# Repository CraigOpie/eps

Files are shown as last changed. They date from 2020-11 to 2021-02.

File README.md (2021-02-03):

# Electronic Power Supply
```

Vendor: Death Star Development, LLC
Date Created: August 1st, 2020
Version: 0.4.0

License: CC BY-NC-ND
Associated Filename: All
Associated Document: 
      https://github.com/craigopie/eps

```
------------------------------------------------------------------------------------
```

Disclaimer:

      This disclaimer is not a license and does not grant any rights to
      the materials distributed herewith. Except as otherwise provided in
      a valid license issued to you by DSD, and to the maximum extent
      permitted by applicable law: (1) THESE MATERIALS ARE MADE AVAILABLE
      "AS IS" AND WITH ALL FAULTS, AND DSD HEREBY DISCLAIMS ALL
      WARRANTIES AND CONDITIONS, EXPRESS, IMPLIED, OR STATUTORY,
      INCLUDING BUT NOT LIMITED TO THE WARRANTIES OF MERCHANTABILITY,
      NON-INFRINGEMENT, OR FITNESS FOR ANY PARTICULAR PURPOSE; and
      (2) DSD shall not be liable (whether in contract or tort,
      including negligence, or under any other theory of liability) for
      any loss or damage of any kind or nature related to, arising under
      or in connection with these materials, including any direct, or
      any indirect, special, incidental, or consequential loss or damage
      (including loss of data, profits, goodwill, or any type of loss or
      damage suffered as a result of any action brought by a third party)
      even if such damage or loss was reasonably foreseeable or DSD
      had been advised of the possibility of the same.

Critical Applications:

      DSD products are not designed or intended to be fail-safe, or
      for use in any application requiring fail-safe performance, such as
      life-support or safety devices or systems, Class III medical
      devices, nuclear facilities, applications related to the deployment
      of airbags, or any other applications that could lead to death,
      personal injury, or severe property or environmental damage
      (individually and collectively, "Critical Applications"). Customer
      assumes the sole risk and liability of any use of DSD products
      in Critical Applications, subject only to applicable laws and
      regulations governing limitations on product liability.

THIS COPYRIGHT NOTICE AND DISCLAIMER MUST BE RETAINED AS PART OF THIS
FILE AT ALL TIMES.

```
------------------------------------------------------------------------------------

# Overview

### Introduction

This repository provides a low cost Electronic Power Supply (EPS) in a PC-104 form factor that can be assembled by low experience individuals with limited soldering equipment.  The design provides the choice of using an Arduino controller or an ATSAM3X8E 32-bit processor.  The ATSAM3X8E provides more reliable I2C communications.  

### Notes

This version does not have a working WatchDog Timer.

### Features

Supports 8.2 Volt Batteries (2S Cell Lithium Based Chemistry).
* (6) Solar Pannel Connections
* (1) USB-C Connection for Programming
* (1) Arduino Nano Every as the Micro-Controller
* (3) 3V3 Switched Power Supplies (2A Max ea.)
* (2) 5V Switched Power Supplies (2A Max ea.)
* (1) 3V3 Bus Power Supply (2A Max)
* (1) 5V Bus Power Supply (2A Max)
* (1) I2C Bus Interface
* (1) Serial (UART) Interface

# Build

### Hardware

Please review the BOM and populate as required by referencing the schematic.  The 5V bus IC requires the supply and enable pins to be shorted together, using a solder bridge, during manufacturing.

### Firmware

Arduino: Be sure to flash the software and test the functionality prior to soldering on to the EPS. <br />
ATSAM3X8E: Please follow the documentation provided for the Arduino Due programming using the Native Port.

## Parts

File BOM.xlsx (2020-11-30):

Reference Designator | Value | Manufacturer Part Number | Digikey Part Number | Other Resource
C1 | 33pF | CL10C330JB8NNNC | 1276-1070-1-ND
C2, C3, C7 | 1uF | ‎CL10B105KA8NNNC | 1276-1184-1-ND
C33 | 22uF | T521V226M025ATE040 | 399-13114-1-ND
C34, C38, C39 | 4.7uF | CL31B475KAHNNNE | 1276-1055-1-ND
C4, C5, C64, C71, C72, C74, C75, C76, C77, C78, C79, C81, C83, C85, C86, C87, C88, C89, C90, C97 | 0.1uF | CL10B104KA8NNNC | 1276-1006-1-ND
C40, C43, C47, C52, C57, C58, C60, C61, C62 | 0.1uF | CL21B104KACNNNC | 1276-1099-1-ND
C41, C42, C48, C53, C59, C65, C66, C67, C68, C69 | 1uF | CL21B105KOFNNNG | 1276-6471-1-ND
C44, C49, C54 | 10pF | CL21C100CBANNNC | 1276-2561-1-ND
C45, C50, C55 | 47uF | CL32A476KOJNNNE | 1276-3376-1-ND
C46, C51, C56 | 4.7uF | CL21A475KAQNNNE | 1276-1244-1-ND
C6, C9 | 10uF | CL31B106MOHNNNE | 1276-6641-1-ND
C63 | 10000pF | CL21B103KBANNNC | 1276-1015-1-ND
C70, C73, C80, C82, C84, C98 | 22uF | CL10A226MO7JZNC | 1276-7076-1-ND
C8, C10, C101 | 4.7uF | CL10A475KO8NNNC | 1276-1784-1-ND
C91 | 10000pF | CL10B103KB8NNNC | 1276-1009-1-ND
C92, C93, C94, C95, C96 | 22pF | CL10C220JB8NFNC | 1276-2228-1-ND
D1, D2, D3, D4, D5, D6, D7 | DNP | MBR2H100SFT3G | MBR2H100SFT3GOSCT-ND
D8 | 1N5819HW | 1N5819HW-7-F | 1N5819HW-FDICT-ND
FB3 | 330 | BLM21SP331SH1D | 490-18586-1-ND
FB4, FB5, FB6, FB7 | MH2029-300Y | MH2029-300Y | MH2029-300YCT-ND
J7 | CONN_2X5_127 | 20021121-00010C4LF | 609-3695-1-ND
J8 | USB-C | UJ31-CH-G1-SMT-TR | 102-4488-1-ND
L1 | IND-FXL0630 | FXL0630-2R2-M |  | https://lcsc.com/product-detail/Power-Inductors_Changjiang-Microelectronics-Tech-FXL0630-2R2-M_C167218.html
L4, L5, L6 | 2.2uH | XFL4020-222MEC |  | https://www.mouser.com/ProductDetail/Coilcraft/XFL4020-222MEC?qs=zCSbvcPd3pbe5jEAG1ZkEA%3D%3D
M1 | A03400 | A03400 |  | https://lcsc.com/product-detail/MOSFET_KEXIN-AO3400_C382311.html
R1, R10, R44 | 10K | RC1608J103CS | 1276-5086-1-ND
R15, R16, R18, R70 | 1K | RC1608F102CS | 1276-3484-1-ND
R17 | 100 | RC1608F101CS | 1276-3482-1-ND
R2 | 40.2K | RC1608F4022CS | 1276-4800-1-ND
R3 | 86.6K / 84.5K | RC1608F8452CS | 1276-4833-1-ND
R31, R32, R33, R34, R60 | 1M | RC1608J105CS | 1276-5134-1-ND
R39, R45, R51 | 18.2K | RC2012F1822CS | 1276-5349-1-ND
R4 | 71.5K / 68.1K | RC1608F6812CS | 1276-4824-1-ND
R40, R48 | 182K / 180K | RC2012F184CS | 1276-5408-1-ND
R41, R47, R53 | 1.0M | RC2012F105CS | 1276-5440-1-ND
R42, R46, R52 | 49.9K / 47K | RC2012J473CS | 1276-5568-1-ND
R43, R50, R56, R62, R63, R64, R69, R75, R76 | 100K | RC1608J104CS | 1276-5110-1-ND
R5 | 15K | RC2012J153CS | 1276-5556-1-ND
R54 | 300K / 301K | RC2012F3013CS | 1276-5424-1-ND
R55 | 62K / 63.4K | RC2012F6342CS | 1276-5383-1-ND
R59 | 127K / 130K | RC2012F134CS | 1276-5400-1-ND
R6, R37, R38, R57 | 10K | RC2012F103CS | 1276-5332-1-ND
R61 | 191K / 180K | RC2012F184CS | 1276-5408-1-ND
R65, R66 | 39R 1% | RC1608F390CS | 1276-4531-1-ND
R67 | 6.8K | RC1608F6811CS | 1276-4729-1-ND
R68 | 0 | RC1005J000CS | 1276-3480-1-ND
R7, R8, R30, R36, R58 | 2K | RC1608F202CS | 1276-3495-1-ND
R73, R74 | 5.1K | RC1608F512CS | 1276-4713-1-ND
R9 | 27.4K | RC1608F2742CS | 1276-4782-1-ND
R99 | 0 | CRCW20100000Z0EF | 541-0.0WCT-ND
TB1 | ARDUINO_NANO | ARDUINO_NANO
U1 | MP2639A | MP2639AGR-Z | 1589-1618-1-ND
U11 | ADT7311 | ADT7311WTRZ-RL7 | ADT7311WTRZ-RL7CT-ND
U12 | MAX16998AAUA+ | MAX16998AAUA+ | MAX16998AAUA+-ND
U13 | Value | TPS27082LDDCR | 296-35595-1-ND
U14 | ATSAM3X8EA-AU | ATSAM3X8EA-AU | ATSAM3X8EA-AU-ND
U15, U18 | PMV48XP | PMV48XPAR | 1727-2308-1-ND
U16 | BC847B-7-F | BC847B-7-F | BC847B-7FDICT-ND
U17 | LMV358IDGKR | LMV358IDGKR | 296-13455-1-ND
U19 | NCP1117ST33T3G | NCP1117ST33T3G | NCP1117ST33T3GOSCT-ND
U2 | TCA9511A | TCA9511A | 296-TCA9511ADGKRCT-ND
U3, U4, U5 | LT8609A | LT8609A | LT8609AEMSE#TRPBFCT-ND
U6, U7, U8, U9, U10 | LTC1477 | LTC1477 | LTC1477CS8#TRPBFCT-ND
Y1 | ABM8 | ABM8-12.000MHZ-12-B1U-T | 535-14962-1-ND
Y2 | FC-135R | FC-135R 32.7680KF-A3 | SER4076CT-ND

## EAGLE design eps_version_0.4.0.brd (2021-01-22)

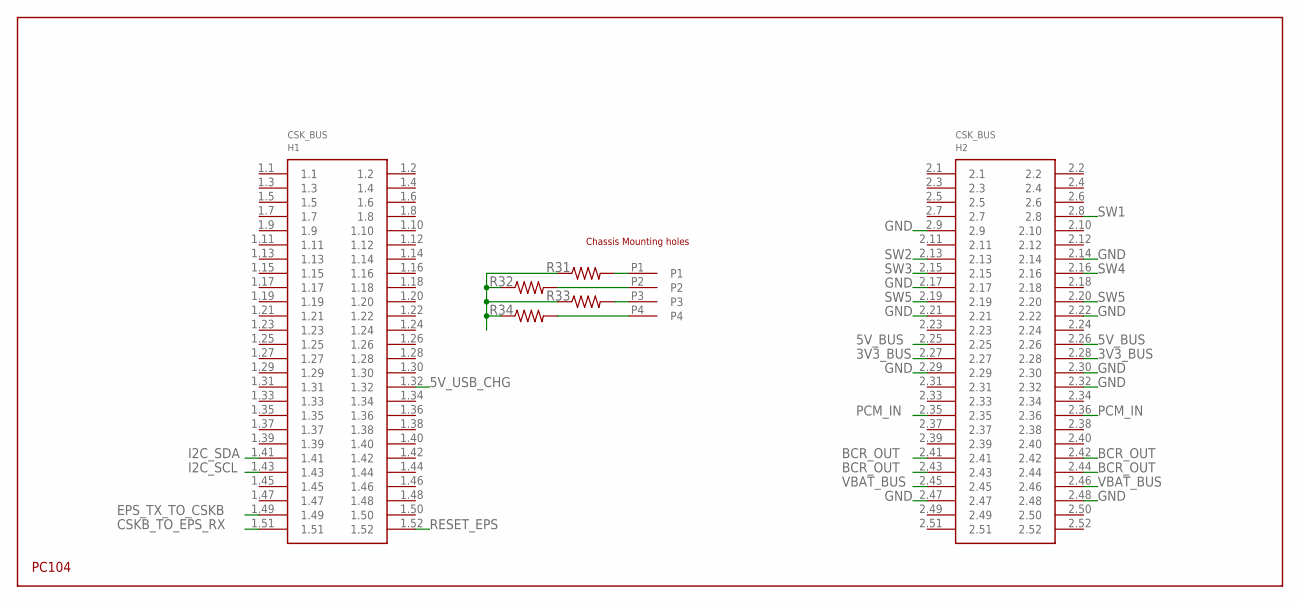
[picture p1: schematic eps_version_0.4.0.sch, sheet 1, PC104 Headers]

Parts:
H1: PC104_WCONN
R31, R32, R33, R34: 1M; 0805

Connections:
3V3_BUS: H1.2.27, H1.2.28; also elsewhere on the board
5V_BUS: H1.2.25, H1.2.26; also elsewhere on the board
5V_USB_CHG: H1.1.32; also elsewhere on the board
BCR_OUT: H1.2.41, H1.2.42, H1.2.43, H1.2.44; also elsewhere on the board
CSKB_TO_EPS_RX: H1.1.51; also elsewhere on the board
EPS_TX_TO_CSKB: H1.1.49; also elsewhere on the board
GND: H1.2.9, H1.2.14, H1.2.17, H1.2.21, H1.2.22, H1.2.29, H1.2.30, H1.2.32, H1.2.47, H1.2.48, R31.1, R32.1, R33.1, R34.1; also elsewhere on the board
I2C_SCL: H1.1.43; also elsewhere on the board
I2C_SDA: H1.1.41; also elsewhere on the board
P1_R31: H1.P1, R31.2
P2_R32: H1.P2, R32.2
P3_R33: H1.P3, R33.2
P4_R34: H1.P4, R34.2
PCM_IN: H1.2.35, H1.2.36; also elsewhere on the board
RESET_EPS: H1.1.52; also elsewhere on the board
SW1: H1.2.8; also elsewhere on the board
SW2: H1.2.13; also elsewhere on the board
SW3: H1.2.15; also elsewhere on the board
SW4: H1.2.16; also elsewhere on the board
SW5: H1.2.19, H1.2.20; also elsewhere on the board
VBAT_BUS: H1.2.45, H1.2.46; also elsewhere on the board

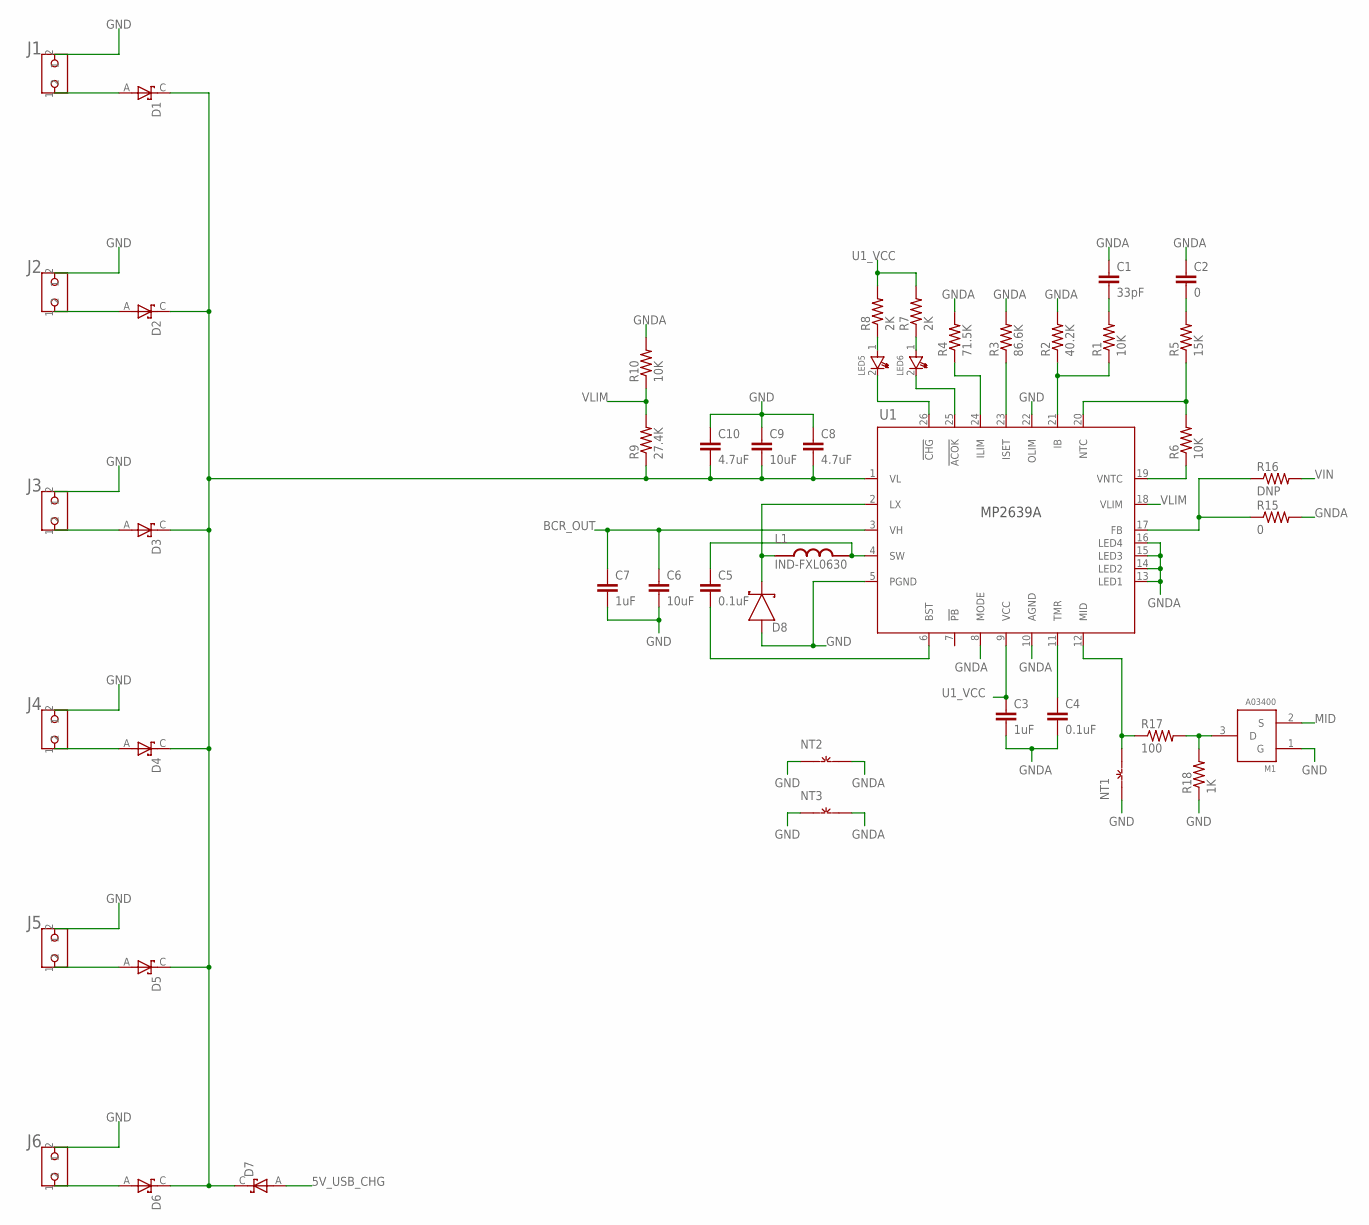
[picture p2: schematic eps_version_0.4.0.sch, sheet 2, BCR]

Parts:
C1: 33pF; 0603-CAP
C2: 0; 0603-CAP
C3, C7: 1uF; 0603-CAP
C4, C5: 0.1uF; 0603-CAP
C6, C9: 10uF; 1206
C8, C10: 4.7uF; 0603-CAP
D1, D2, D3, D4, D5, D6, D7: DNP; SODFL3616X98N
D8: 1N5819HW; SOD123
J1, J2, J3, J4, J5, J6: 2PIN_HEADER; 2MM_2PIN_HEADER
L1: IND-FXL0630; FXL0630
LED5, LED6: LED_0805
M1: A03400; SOT23
NT1, NT2, NT3: GND-GNDA1,27MM; GND-GNDA-1,27MM
R1, R10: 10K; 0603-RES
R2: 40.2K; 0603-RES
R3: 86.6K; 0603-RES
R4: 71.5K; 0603-RES
R5: 15K; 0805
R6: 10K; 0805
R7, R8: 2K; 0603-RES
R9: 27.4K; 0603-RES
R15: 0; 0603-RES
R16: DNP; 0603-RES
R17: 100; 0603-RES
R18: 1K; 0603-RES
U1: MP2639A; IC26_MP2639A_MNP

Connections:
5V_USB_CHG: D7.A; also elsewhere on the board
!ACOK: LED6.2, U1.25 (!ACOK)
!CHG: LED5.2, U1.26 (!CHG)
BCR_OUT: C6.1, C7.1, U1.3 (VH); also elsewhere on the board
BST: C5.2, U1.6 (BST)
C1_R1: C1.2, R1.2
GND: C6.2, C7.2, C8.1, C9.1, C10.1, D8.2 (1), J1.2, J2.2, J3.2, J4.2, J5.2, J6.2, M1.1 (G), NT1.GND, NT2.GND, NT3.GND, R18.1, U1.5 (PGND), U1.22 (OLIM); also elsewhere on the board
GNDA: C1.1, C2.1, C3.2, C4.2, NT2.GNDA, NT3.GNDA, R2.2, R3.2, R4.2, R10.2, R15.2, U1.8 (MODE), U1.10 (AGND), U1.13 (LED1), U1.14 (LED2), U1.15 (LED3), U1.16 (LED4)
IB: R1.1, R2.1, U1.21 (IB)
ILIM: R4.1, U1.24 (ILIM)
ISET: R3.1, U1.23 (ISET)
LX: D8.1 (2), L1.1, U1.2 (LX)
MID: M1.2 (S), NT1.GNDA, R17.1, U1.12 (MID)
NTC: R5.1, R6.2, U1.20 (NTC)
R5_C2: C2.2, R5.2
R7_LED6: LED6.1, R7.1
R8_LED5: LED5.1, R8.1
R17_R18: M1.3 (D), R17.2, R18.2
SA1AIN: D1.A, J1.1
SA1BIN: D2.A, J2.1
SA2AIN: D3.A, J3.1
SA2BIN: D4.A, J4.1
SA3AIN: D5.A, J5.1
SA3BIN: D6.A, J6.1
TMR: C4.1, U1.11 (TMR)
U1_FB: R15.1, R16.1, U1.17 (FB)
U1_SW: C5.1, L1.2, U1.4 (SW)
U1_VCC: C3.1, R7.2, R8.2, U1.9 (VCC)
VIN: C8.2, C9.2, C10.2, D1.C, D2.C, D3.C, D4.C, D5.C, D6.C, D7.C, R9.1, R16.2, U1.1 (VL)
VLIM: R9.2, R10.1, U1.18 (VLIM)
VNTC: R6.1, U1.19 (VNTC)

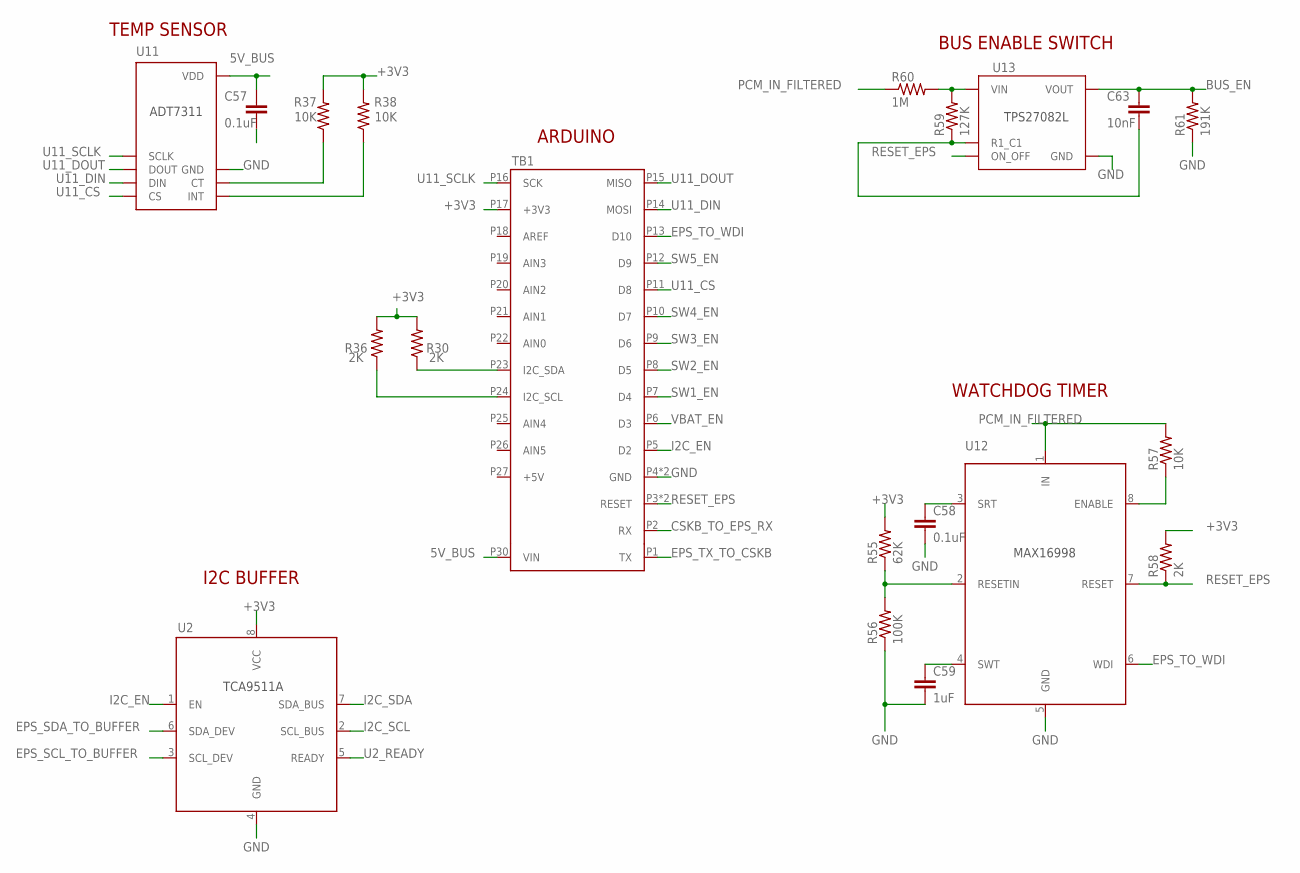
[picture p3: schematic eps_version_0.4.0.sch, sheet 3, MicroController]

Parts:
C57, C58: 0.1uF; 0805
C59: 1uF; 0805
C63: 10nF; 0805
R30, R36, R58: 2K; 0805
R37, R38, R57: 10K; 0805
R55: 62K; 0805
R56: 100K; 0805
R59: 127K; 0805
R60: 1M; 0805
R61: 191K; 0805
TB1: ARDUINO_NANO; SHIELD_ARDUINO_NANO
U2: TCA9511A; SOP65P490X110-8N
U11: ADT7311; SOIC-8
U12: MAX16998AAUA+; 21-0036K_MXM
U13: Value; DDC0006A_N

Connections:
5V_BUS: C57.1, TB1.P30 (VIN), U11.8 (VDD); also elsewhere on the board
+3V3: R30.2, R36.2, R37.2, R38.2, R55.2, R58.2, TB1.P17 (+3V3), U2.8 (VCC)
BUS_EN: C63.1, R61.2, U13.2 (VOUT), U13.3 (VOUT); also elsewhere on the board
CSKB_TO_EPS_RX: TB1.P2 (RX); also elsewhere on the board
EPS_SCL_TO_BUFFER: R36.1, TB1.P24 (I2C_SCL), U2.3 (SCL_DEV); also elsewhere on the board
EPS_SDA_TO_BUFFER: R30.1, TB1.P23 (I2C_SDA), U2.6 (SDA_DEV); also elsewhere on the board
EPS_TO_WDI: TB1.P13 (D10), U12.6 (WDI); also elsewhere on the board
EPS_TX_TO_CSKB: TB1.P1 (TX); also elsewhere on the board
GND: C57.2, C58.2, C59.2, R56.1, R61.1, TB1.P4 (GND), TB1.P29 (GND), U2.4 (GND), U11.7 (GND), U12.5 (GND), U13.1 (GND); also elsewhere on the board
I2C_EN: TB1.P5 (D2), U2.1 (EN); also elsewhere on the board
I2C_SCL: U2.2 (SCL_BUS); also elsewhere on the board
I2C_SDA: U2.7 (SDA_BUS); also elsewhere on the board
PCM_IN_FILTERED: R57.2, R60.1, U12.1 (IN); also elsewhere on the board
PCM_IN_FILTERED_TO_BUS_EN: R59.2, R60.2, U13.4 (VIN)
RESET_EPS: R58.1, TB1.P3 (RESET), TB1.P28 (RESET), U12.7 (RESET), U13.5 (ON_OFF); also elsewhere on the board
SW1_EN: TB1.P7 (D4); also elsewhere on the board
SW2_EN: TB1.P8 (D5); also elsewhere on the board
SW3_EN: TB1.P9 (D6); also elsewhere on the board
SW4_EN: TB1.P10 (D7); also elsewhere on the board
SW5_EN: TB1.P12 (D9); also elsewhere on the board
U2_READY: U2.5 (READY)
U11_CS: TB1.P11 (D8), U11.4 (CS); also elsewhere on the board
U11_CT: R37.1, U11.6 (CT)
U11_DIN: TB1.P14 (MOSI), U11.3 (DIN); also elsewhere on the board
U11_DOUT: TB1.P15 (MISO), U11.2 (DOUT); also elsewhere on the board
U11_INT: R38.1, U11.5 (INT)
U11_SCLK: TB1.P16 (SCK), U11.1 (SCLK); also elsewhere on the board
U12_EN_ALT: R57.1, U12.8 (ENABLE)
U12_RESETIN: R55.1, R56.2, U12.2 (RESETIN)
U12_SRT: C58.1, U12.3 (SRT)
U12_SWT: C59.1, U12.4 (SWT)
U13_R60_C63: C63.2, R59.1, U13.6 (R1_C1)
VBAT_EN: TB1.P6 (D3); also elsewhere on the board

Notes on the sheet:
I2C BUFFER
ARDUINO
TEMP SENSOR
WATCHDOG TIMER
BUS ENABLE SWITCH

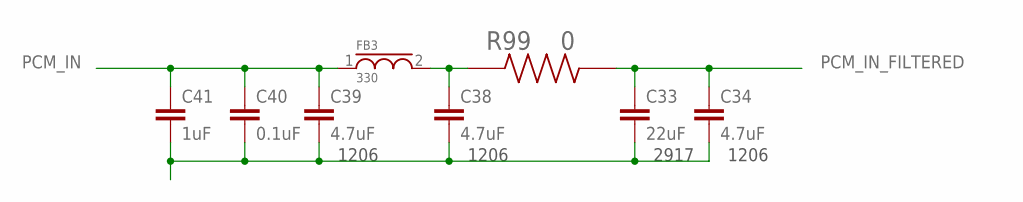
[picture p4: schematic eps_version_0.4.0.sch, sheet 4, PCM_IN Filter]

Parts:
C33: 22uF; CAPMP7343X430N
C34, C38, C39: 4.7uF; 1206
C40: 0.1uF; 0805
C41: 1uF; 0805
FB3: 330; 0805
R99: 0; RESC5025X70N

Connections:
FB3_L3: C38.1, FB3.2, R99.1
GND: C33.2, C34.2, C38.2, C39.2, C40.2, C41.2; also elsewhere on the board
PCM_IN: C39.1, C40.1, C41.1, FB3.1; also elsewhere on the board
PCM_IN_FILTERED: C33.1, C34.1, R99.2; also elsewhere on the board

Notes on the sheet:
1206
2917

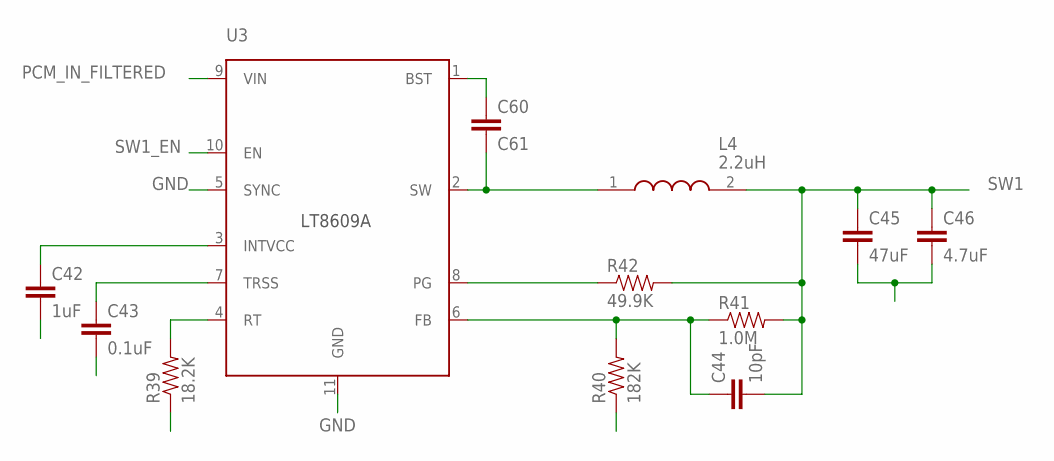
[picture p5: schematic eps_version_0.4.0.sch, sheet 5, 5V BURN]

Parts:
C42: 1uF; 0805
C43: 0.1uF; 0805
C44: 10pF; 0805
C45: 47uF; 1210
C46: 4.7uF; 0805
C60: C61; 0805
L4: 2.2uH; XFL4030472MEB
R39: 18.2K; 0805
R40: 182K; 0805
R41: 1.0M; 0805
R42: 49.9K; 0805
U3: LT8609A; MSOP-10_MSE

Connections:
FB_SW1: C44.1, R40.2, R41.1, U3.6 (FB)
GND: C42.2, C43.2, C45.2, C46.2, R39.1, R40.1, U3.5 (SYNC), U3.11 (GND); also elsewhere on the board
PCM_IN_FILTERED: U3.9 (VIN); also elsewhere on the board
PG_SW1: R42.1, U3.8 (PG)
RT_SW1: R39.2, U3.4 (RT)
SW1: C44.2, C45.1, C46.1, L4.2, R41.2, R42.2; also elsewhere on the board
SW1_EN: U3.10 (EN); also elsewhere on the board
SW_SW1: C60.2, L4.1, U3.2 (SW)
TRSS_SW1: C43.1, U3.7 (TRSS)
U3_BST: C60.1, U3.1 (BST)
VCC_SW1: C42.1, U3.3 (INTVCC)

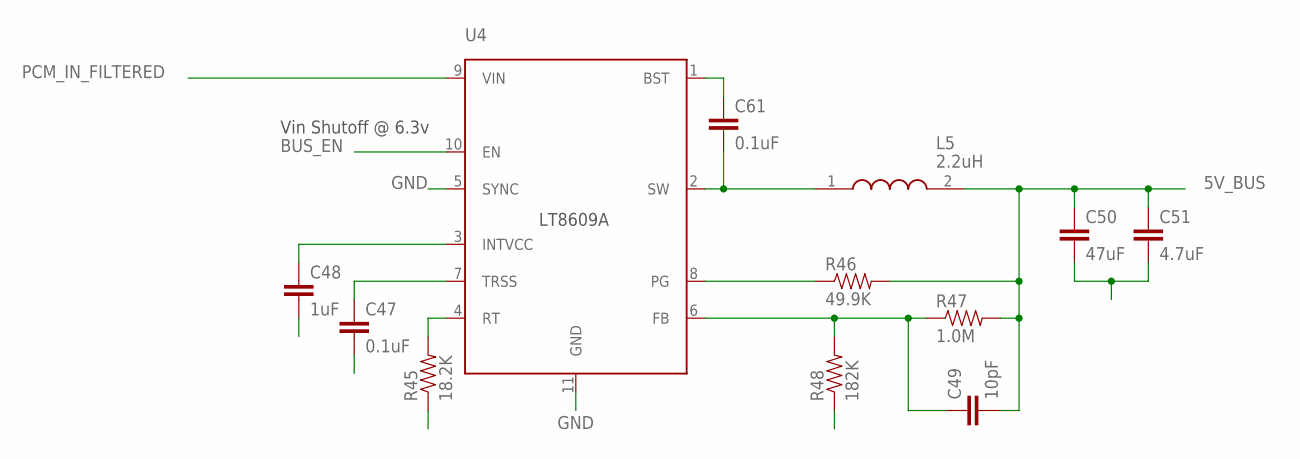
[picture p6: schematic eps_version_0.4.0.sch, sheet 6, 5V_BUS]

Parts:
C47, C61: 0.1uF; 0805
C48: 1uF; 0805
C49: 10pF; 0805
C50: 47uF; 1210
C51: 4.7uF; 0805
L5: 2.2uH; XFL4030472MEB
R45: 18.2K; 0805
R46: 49.9K; 0805
R47: 1.0M; 0805
R48: 182K; 0805
U4: LT8609A; MSOP-10_MSE

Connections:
5V_BUS: C49.2, C50.1, C51.1, L5.2, R46.2, R47.2; also elsewhere on the board
BST_5V_BUS: C61.1, U4.1 (BST)
BUS_EN: U4.10 (EN); also elsewhere on the board
FB_5V_BUS: C49.1, R47.1, R48.2, U4.6 (FB)
GND: C47.2, C48.2, C50.2, C51.2, R45.1, R48.1, U4.5 (SYNC), U4.11 (GND); also elsewhere on the board
PCM_IN_FILTERED: U4.9 (VIN); also elsewhere on the board
PG_5V_BUS: R46.1, U4.8 (PG)
RT_5V_BUS: R45.2, U4.4 (RT)
SW_5V_BUS: C61.2, L5.1, U4.2 (SW)
TRSS_5V_BUS: C47.1, U4.7 (TRSS)
VCC_5V_BUS: C48.1, U4.3 (INTVCC)

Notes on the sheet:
Vin Shutoff @ 6.3v

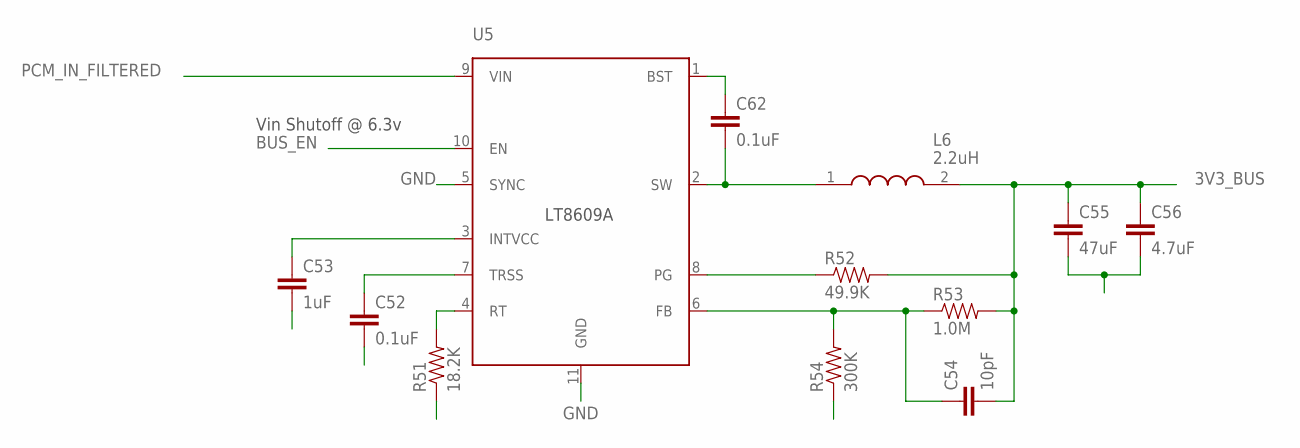
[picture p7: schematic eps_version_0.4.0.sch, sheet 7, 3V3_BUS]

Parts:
C52, C62: 0.1uF; 0805
C53: 1uF; 0805
C54: 10pF; 0805
C55: 47uF; 1210
C56: 4.7uF; 0805
L6: 2.2uH; XFL4030472MEB
R51: 18.2K; 0805
R52: 49.9K; 0805
R53: 1.0M; 0805
R54: 300K; 0805
U5: LT8609A; MSOP-10_MSE

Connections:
3V3_BUS: C54.2, C55.1, C56.1, L6.2, R52.2, R53.2; also elsewhere on the board
BST_3V3_BUS: C62.1, U5.1 (BST)
BUS_EN: U5.10 (EN); also elsewhere on the board
FB_3V3_BUS: C54.1, R53.1, R54.2, U5.6 (FB)
GND: C52.2, C53.2, C55.2, C56.2, R51.1, R54.1, U5.5 (SYNC), U5.11 (GND); also elsewhere on the board
PCM_IN_FILTERED: U5.9 (VIN); also elsewhere on the board
PG_3V3_BUS: R52.1, U5.8 (PG)
RT_3V3_BUS: R51.2, U5.4 (RT)
SW_3V3_BUS: C62.2, L6.1, U5.2 (SW)
TRSS_3V3_BUS: C52.1, U5.7 (TRSS)
VCC_3V3_BUS: C53.1, U5.3 (INTVCC)

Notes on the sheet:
Vin Shutoff @ 6.3v

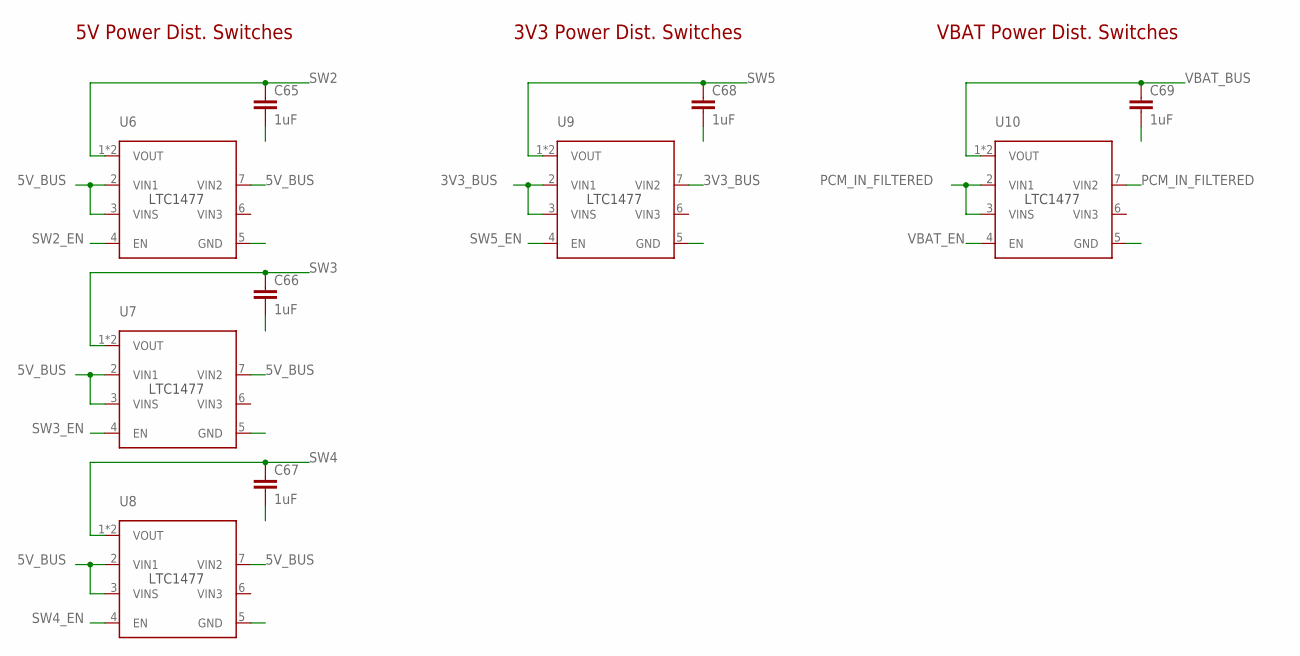
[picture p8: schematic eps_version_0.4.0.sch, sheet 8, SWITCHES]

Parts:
C65, C66, C67, C68, C69: 1uF; 0805
U6, U7, U8, U9, U10: LTC1477; SO8

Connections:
3V3_BUS: U9.2 (VIN1), U9.3 (VINS), U9.7 (VIN2); also elsewhere on the board
5V_BUS: U6.2 (VIN1), U6.3 (VINS), U6.7 (VIN2), U7.2 (VIN1), U7.3 (VINS), U7.7 (VIN2), U8.2 (VIN1), U8.3 (VINS), U8.7 (VIN2); also elsewhere on the board
GND: C65.2, C66.2, C67.2, C68.2, C69.2, U6.5 (GND), U7.5 (GND), U8.5 (GND), U9.5 (GND), U10.5 (GND); also elsewhere on the board
PCM_IN_FILTERED: U10.2 (VIN1), U10.3 (VINS), U10.7 (VIN2); also elsewhere on the board
SW2: C65.1, U6.1 (VOUT), U6.8 (VOUT); also elsewhere on the board
SW2_EN: U6.4 (EN); also elsewhere on the board
SW3: C66.1, U7.1 (VOUT), U7.8 (VOUT); also elsewhere on the board
SW3_EN: U7.4 (EN); also elsewhere on the board
SW4: C67.1, U8.1 (VOUT), U8.8 (VOUT); also elsewhere on the board
SW4_EN: U8.4 (EN); also elsewhere on the board
SW5: C68.1, U9.1 (VOUT), U9.8 (VOUT); also elsewhere on the board
SW5_EN: U9.4 (EN); also elsewhere on the board
VBAT_BUS: C69.1, U10.1 (VOUT), U10.8 (VOUT); also elsewhere on the board
VBAT_EN: U10.4 (EN); also elsewhere on the board

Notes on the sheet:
5V Power Dist. Switches
3V3 Power Dist. Switches
VBAT Power Dist. Switches

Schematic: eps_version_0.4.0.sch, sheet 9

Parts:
C64, C71, C72, C74, C75, C76, C77, C78, C79, C81, C83, C85, C86, C87, C88, C89, C90, C97: 100nF; 0603-CAP
C70, C73, C80, C82, C84, C98: 22uF; 0603-CAP
C91: 10nF; 0603-CAP
C92, C93, C94, C95, C96: 22pF; 0603-CAP
C101: 4.7uF; 0603-CAP
FB4, FB5: MH2029-300Y; 0805
FB6, FB7: FB0805; 0805
J7: CONN_2X5_127; 2X5_127
J8: USB-C; CUI_UJ31-CH-G1-SMT-TR
R43, R50, R62, R63, R64, R69, R75, R76: 100K; 0603-RES
R44: 10K; 0603-RES
R65, R66: 39R 1%; 0603-RES
R67: 6.8K; 0603-RES
R68: 0; 0402-RES
R70: 1K; 0603-RES
R73, R74: 5.1K; 0603-RES
U14: ATSAM3X8EA-AU; LQFP144
U15: PMV48XP; TO-236_SOT23_NEX
U16: BC847B-7-F; TO-236_SOT23_NEX
U17: LMV358IDGKR; DGK8
U18: PMV48XP,215; TO-236_SOT23_NEX
U19: NCP1117ST33T3G; SOT223-3_ONS
Y1: ABM8
Y2: FC-135R; FC-135

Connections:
3V3: C72.1, C73.1, C74.1, C75.1, C76.1, C77.1, C78.1, C79.1, C91.1, C98.1, FB5.1, FB6.1, FB7.1, J7.1, R43.2, R44.2, R50.2, R62.2, R63.2, R64.2, U14.11 (VDDIO1), U14.52 (VDDBU), U14.57 (VDDIN), U14.62 (VDDIO2), U14.105 (VDDIO3), U14.125 (VDDIO4), U15.2 (S), U17.6 (2IN-), U19.2 (OUT)
5V_BUS: R69.2, U17.8 (VCC+), U18.2 (S), U19.3 (IN); also elsewhere on the board
5V_BUS_U17_+: C97.1, R69.1, R76.2, U16.3 (C), U17.5 (2IN+)
AVREF: C64.1, FB5.2, U14.75 (ADVREF)
CC1: J8.A5 (CC1), R74.2
CC2: J8.B5 (CC2), R73.2
CSKB_TO_EPS_RX: U14.27 (PA8); also elsewhere on the board
EPS_SCL_TO_BUFFER: U14.70 (PA18); also elsewhere on the board
EPS_SDA_TO_BUFFER: U14.9 (PA17); also elsewhere on the board
EPS_TO_WDI: U14.144 (PB25); also elsewhere on the board
EPS_TX_TO_CSKB: U14.2 (PA9); also elsewhere on the board
ERASE_CMD: R44.1, U15.1 (G)
ERASE_S: U14.130 (PC0), U15.3 (D)
FWUP_R43: R43.1, U14.53 (FWUP)
GND: C64.2, C70.2, C71.2, C72.2, C73.2, C74.2, C75.2, C76.2, C77.2, C78.2, C79.2, C80.2, C81.2, C82.2, C83.2, C84.2, C85.2, C86.2, C87.2, C88.2, C89.2, C90.2, C92.2, C93.1, C94.2, C95.2, C96.1, C97.2, C98.2, C101.2, J7.3, J7.5, J7.9, J8.A1 (GND), J8.A12 (GND), J8.B1 (GND), J8.B12 (GND), J8.SH1 (SHIELD), J8.SH2 (SHIELD), J8.SH3 (SHIELD), J8.SH4 (SHIELD), J8.SH5 (SHIELD), J8.SH6 (SHIELD), R67.1, R68.1, R73.1, R74.1, R75.1, R76.1, U14.12 (GND1), U14.33 (GNDPLL), U14.44 (GNDUTMI), U14.46 (JTAGSEL), U14.54 (GNDBU), U14.58 (GND2), U14.74 (GNDANA), U14.106 (GND3), U14.126 (GND4), U16.2 (E), U17.4 (GND), U19.1 (GND), Y1.2, Y1.4; also elsewhere on the board
I2C_EN: U14.139 (PC28); also elsewhere on the board
JTAG_TCK: J7.4, R62.1, U14.28 (PB28)
JTAG_TDI: J7.8, R63.1, U14.29 (PB29)
JTAG_TDO: J7.6, U14.30 (PB30)
JTAG_TMS: J7.2, R50.1, U14.31 (PB31)
R65_DFSDM: R65.2, U14.43 (DFSDM)
R66_DFSDP: R66.2, U14.42 (DFSDP)
R68_TST: R68.2, U14.51 (TST)
R70_U16_BASE: R70.2, R75.2, U16.1 (B)
RESET_EPS: C91.2, J7.10, R64.1, U14.47 (NRSTB); also elsewhere on the board
SW1_EN: U14.136 (PC25); also elsewhere on the board
SW2_EN: U14.135 (PC24); also elsewhere on the board
SW3_EN: U14.134 (PC23); also elsewhere on the board
SW4_EN: U14.133 (PC22); also elsewhere on the board
SW5_EN: U14.132 (PC21); also elsewhere on the board
U11_CS: U14.111 (PA28); also elsewhere on the board
U11_DIN: U14.20 (PD7); also elsewhere on the board
U11_DOUT: U14.21 (PD8); also elsewhere on the board
U11_SCLK: U14.88 (PB17); also elsewhere on the board
U17_U18: U17.7 (2OUT), U18.1 (G)
USB_DM: J8.A7 (DN1), J8.B7 (DN2), R65.1, U14.38 (DHSDM)
USB_DP: J8.A6 (DP1), J8.B6 (DP2), R66.1, U14.37 (DHSDP)
USB_OTG_ID: U14.129 (PB11)
USB_OTG_VBOF: R70.1, U14.128 (PB10)
USB_VBUS: C101.1, J8.A4 (VBUS), J8.A9 (VBUS), J8.B4 (VBUS), J8.B9 (VBUS), U14.39 (VBUS), U18.3 (D)
VBAT_EN: U14.112 (PA29); also elsewhere on the board
VBG: C92.1, R67.2, U14.40 (VBG)
VDDANA: C80.1, C81.1, FB6.2, U14.73 (VDDANA)
VDDOUT: C84.1, C85.1, C86.1, C87.1, C88.1, C89.1, C90.1, FB4.1, U14.10 (VDDCORE1), U14.45 (VDDCORE2), U14.56 (VDDOUT), U14.61 (VDDCORE3), U14.104 (VDDCORE4), U14.124 (VDDCORE5)
VDDOUTMI: C82.1, C83.1, FB7.2, U14.41 (VDDOUTMI)
VDDPLL: C70.1, C71.1, FB4.2, U14.34 (VDDPL)
XIN: C93.2, U14.36 (XIN), Y1.3
XIN32: C96.2, U14.48 (XIN32), Y2.2
XOUT: C94.1, U14.35 (XOUT), Y1.1
XOUT32: C95.1, U14.49 (XOUT32), Y2.1

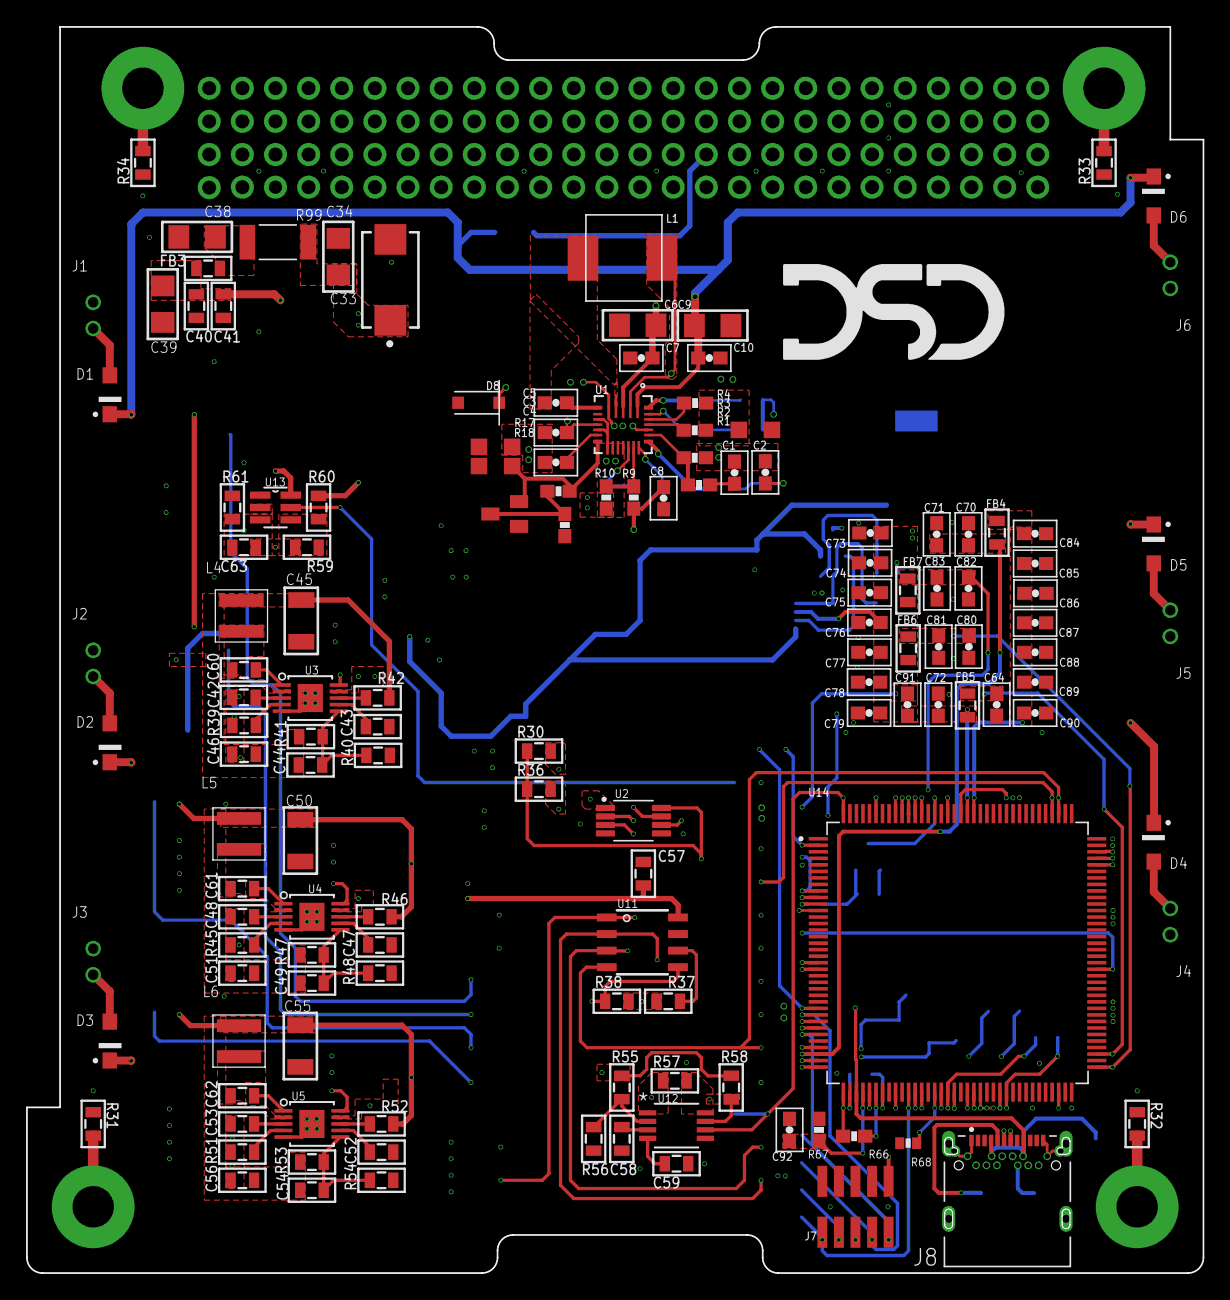
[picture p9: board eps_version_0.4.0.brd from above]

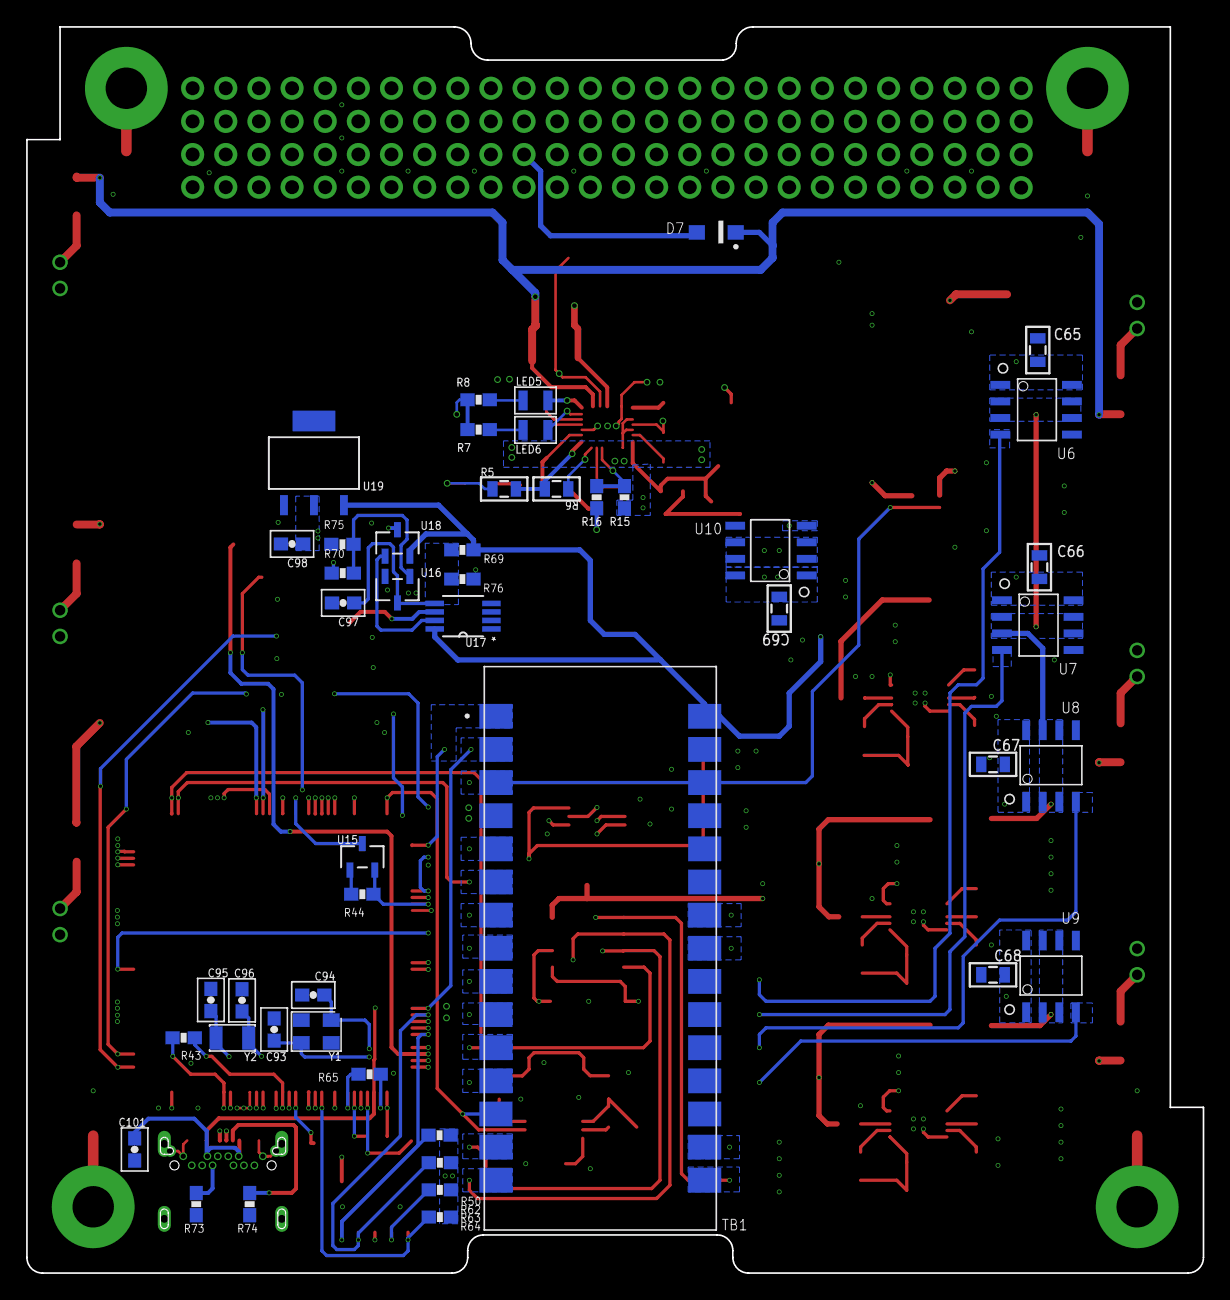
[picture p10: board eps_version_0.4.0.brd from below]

Board: 4 copper layers, 90.2 x 95.5 mm, 186 parts (47 on the bottom side), 126 nets.

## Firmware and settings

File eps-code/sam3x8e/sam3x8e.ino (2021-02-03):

/********************************************************************
 *   
 *   DSD EPS Software
 *   
 *******************************************************************   
 *******************************************************************
 *   Purpose
 *   
 *   Sketch to operate DSD EPS                      
 *                                                                  
 *   Program editors:                                               
 *     Craig Opie                                                   
 *                                                                  
 *******************************************************************/
/********************************************************************
 *   Editing history
 *   
 *   08/04/20 - Version 0.1.0 - Craig:
 *   Initial Draft.
 *   - Standard object code and methods
 *              
 *******************************************************************/
/********************************************************************
 *   Hardware compatibility
 *   
 *   DSD EPS v0.4.0
 *   Arduino Nano Every
 *   
 *******************************************************************/


/********************************************************************
 *   Includes
 *******************************************************************/
#include <Wire.h>


/********************************************************************
 *   Definitions
 *******************************************************************/
#define I2C_ADDRESS                           0x2b
#define BOARD_STATUS                          0x01
#define GET_LAST_ERROR                        0x03
#define GET_VERSION                           0x04
#define GET_TELEMETRY                         0x10
#define GET_WATCHDOG                          0x20
#define SET_WATCHDOG                          0x21
#define RESET_WATCHDOG                        0x22
#define ALL_PDMS_ON                           0x40
#define ALL_PDMS_OFF                          0x41
#define GET_PDMS_ACTUAL                       0x42
#define GET_PDMS_EXPECTED                     0x43
#define SET_PDM_ON                            0x50
#define SET_PDM_OFF                           0x51
#define EPS_RESET                             0x80

#define UART                                  Serial
#define I2C                                   Wire
#define I2C_ENABLE                            139
#define VBAT_ENABLE                           137
#define SW1_ENABLE                            136
#define SW2_ENABLE                            135
#define SW3_ENABLE                            134
#define SW4_ENABLE                            133
#define SW5_ENABLE                            132
#define WDT_RESET                             144

#define MAX_I2C_BYTES                         16


/********************************************************************
 *   Setup Object Links/Pointers
 *******************************************************************/
class DSD_EPS
{
  private:
    unsigned long watchdog_limit;
    unsigned long watchdog_last_reset;
    unsigned long watchdog_internal;
    bool reset_eps;
    int pdm_expected;
    int pdm_status;
    int board_status;
    int last_error;
    void gpioHigh(int);
    void gpioLow(int);
    void boardStatus();
    void getLastError();
    void getVersion();
    void getTelemetry();
    void getWatchdog();
    void setWatchdog();
    void resetWatchdog();
    void allPDMsOn();
    void allPDMsOff();
    void getPDMsActual();
    void getPDMsExpected();
    void setPDMOn();
    void setPDMOff();
    void epsReset();

  public:
    bool i2c_receive;
    bool i2c_request;
    byte i2c_data[MAX_I2C_BYTES];
    int bytes;
    DSD_EPS();
    ~DSD_EPS();
    void init();
    void readI2C();
    void readUART();
    void watchdog();
 
};


/********************************************************************
 *   Private GPIO High:
 *      Description:  See ICD for API
 *      Parameters:   None
 *      Return Val:   None
 *******************************************************************/
void DSD_EPS::gpioHigh(int _pin)
{
  digitalWrite(_pin, HIGH);
  delay(1);
}


/********************************************************************
 *   Private GPIO Low:
 *      Description:  See ICD for API
 *      Parameters:   None
 *      Return Val:   None
 *******************************************************************/
void DSD_EPS::gpioLow(int _pin)
{
  digitalWrite(_pin, LOW);
  delay(1);
}


/********************************************************************
 *   Private Board Status:
 *      Description:  See ICD for API
 *      Parameters:   None
 *      Return Val:   None
 *******************************************************************/
void DSD_EPS::boardStatus()
{
  byte buffer_[2];
  buffer_[1] = this->board_status;
  buffer_[0] = 0x00;
  delay(1);
  I2C.write(buffer_, 2);
}


/********************************************************************
 *   Private Get Last Error:
 *      Description:  See ICD for API
 *      Parameters:   None
 *      Return Val:   None
 *******************************************************************/
void DSD_EPS::getLastError()
{
  byte buffer_[2];
  buffer_[1] = this->last_error;
  buffer_[0] = 0x00;
  delay(1);
  I2C.write(buffer_, 2);
}


/********************************************************************
 *   Private Get Board Version:
 *      Description:  See ICD for API
 *      Parameters:   None
 *      Return Val:   None
 *******************************************************************/
void DSD_EPS::getVersion()
{
  byte buffer_[4];
  buffer_[3] = 0x00;
  buffer_[2] = 0x00;
  buffer_[1] = 0x04;
  buffer_[0] = 0x00;
  delay(1);
  I2C.write(buffer_, 4);
}


/********************************************************************
 *   Private Get Telemetry:
 *      Description:  See ICD for API
 *      Parameters:   None
 *      Return Val:   None
 *******************************************************************/
void DSD_EPS::getTelemetry()
{
  // This is effectively just temperature using SPI
  byte buffer_[2];
  
  /********************************************************************
   *   IIDIODE_OUT - BCR Output Current (14.662757 x ADC Count)
   *******************************************************************/
  if ((this->i2c_data[1] == 0xE2) && (this->i2c_data[2] == 0x84))
  {
    buffer_[1] = 0x10;
    buffer_[0] = 0x00;
    delay(1);
    I2C.write(buffer_, 2);
  }
  
  /********************************************************************
   *   VIDIODE_OUT - BCR Output Voltage (0.008993157 x ADC Count)
   *******************************************************************/
  if ((this->i2c_data[1] == 0xE2) && (this->i2c_data[2] == 0x80))
  {
    buffer_[1] = 0xF3;
    buffer_[0] = 0x06;
    delay(1);
    I2C.write(buffer_, 2);
  }
  
  /********************************************************************
   *   I3V3_DRW - 3V3 Current (0.001327547 x ADC Count)
   *******************************************************************/
  if ((this->i2c_data[1] == 0xE2) && (this->i2c_data[2] == 0x05))
  {
    buffer_[1] = 0xE2;
    buffer_[0] = 0x00;
    delay(1);
    I2C.write(buffer_, 2);
  }
  
  /********************************************************************
   *   I5V_DRW - 5V Current (0.001327547 x ADC Count)
   *******************************************************************/
  if ((this->i2c_data[1] == 0xE2) && (this->i2c_data[2] == 0x05))
  {
    buffer_[1] = 0x79;
    buffer_[0] = 0x01;
    delay(1);
    I2C.write(buffer_, 2);
  }
  
  /********************************************************************
   *   IPCM12V - 12V Bus Current (0.00207 x ADC Count)
   *******************************************************************/
  if ((this->i2c_data[1] == 0xE2) && (this->i2c_data[2] == 0x34))
  {
    buffer_[1] = 0xA9;
    buffer_[0] = 0x00;
    delay(1);
    I2C.write(buffer_, 2);
  }
  
  /********************************************************************
   *   VPCM12V - 12V Bus Voltage (0.01349 x ADC Count)
   *******************************************************************/
  if ((this->i2c_data[1] == 0xE2) && (this->i2c_data[2] == 0x30))
  {
    buffer_[1] = 0x7A;
    buffer_[0] = 0x03;
    delay(1);
    I2C.write(buffer_, 2);
  }
  
  /********************************************************************
   *   IPCMBATV - BAT Bus Current (0.005237 x ADC Count)
   *******************************************************************/
  if ((this->i2c_data[1] == 0xE2) && (this->i2c_data[2] == 0x24))
  {
    buffer_[1] = 0x26;
    buffer_[0] = 0x00;
    delay(1);
    I2C.write(buffer_, 2);
  }
  
  /********************************************************************
   *   VPCMBATV - BAT Bus Voltage (0.008978 x ADC Count)
   *******************************************************************/
  if ((this->i2c_data[1] == 0xE2) && (this->i2c_data[2] == 0x20))
  {
    buffer_[1] = 0x81;
    buffer_[0] = 0x03;
    delay(1);
    I2C.write(buffer_, 2);
  }
  
  /********************************************************************
   *   IPCM5V - 5V Bus Current (0.005237 x ADC Count)
   *******************************************************************/
  if ((this->i2c_data[1] == 0xE2) && (this->i2c_data[2] == 0x14))
  {
    buffer_[1] = 0x26;
    buffer_[0] = 0x00;
    delay(1);
    I2C.write(buffer_, 2);
  }
  
  /********************************************************************
   *   VPCM5V - 5V Bus Voltage (0.005865 x ADC Count)
   *******************************************************************/
  if ((this->i2c_data[1] == 0xE2) && (this->i2c_data[2] == 0x10))
  {
    buffer_[1] = 0x55;
    buffer_[0] = 0x03;
    delay(1);
    I2C.write(buffer_, 2);
  }
  
  /********************************************************************
   *   IPCM3V3 - 3V3 Bus Current (0.005237 x ADC Count)
   *******************************************************************/
  if ((this->i2c_data[1] == 0xE2) && (this->i2c_data[2] == 0x04))
  {
    buffer_[1] = 0x26;
    buffer_[0] = 0x00;
    delay(1);
    I2C.write(buffer_, 2);
  }
  
  /********************************************************************
   *   VPCM3V3 - 3V3 Bus Voltage (0.004311 x ADC Count)
   *******************************************************************/
  if ((this->i2c_data[1] == 0xE2) && (this->i2c_data[2] == 0x00))
  {
    buffer_[1] = 0xFE;
    buffer_[0] = 0x02;
    delay(1);
    I2C.write(buffer_, 2);
  }
  
  /********************************************************************
   *   TBRD - Temperature Data (0.372434 x ADC Count)
   *******************************************************************/
  if ((this->i2c_data[1] == 0xE3) && (this->i2c_data[2] == 0x08))
  {
    buffer_[1] = 0x16;
    buffer_[0] = 0x03;
    delay(1);
    I2C.write(buffer_, 2);
  }
}


/********************************************************************
 *   Private Get Watchdog:
 *      Description:  See ICD for API
 *      Parameters:   None
 *      Return Val:   None
 *******************************************************************/
void DSD_EPS::getWatchdog()
{
  byte buffer_[2];
  buffer_[1] = (this->watchdog_limit / 1000.0 / 60.0);
  buffer_[0] = 0x00;
  delay(1);
  I2C.write(buffer_, 2);
}


/********************************************************************
 *   Private Set Watchdog:
 *      Description:  See ICD for API
 *      Parameters:   None
 *      Return Val:   None
 *******************************************************************/
void DSD_EPS::setWatchdog()
{
  this->watchdog_limit = (unsigned long)((int)this->i2c_data[1] * 60.0 * 1000.0);
}


/********************************************************************
 *   Private Reset Watchdog:
 *      Description:  See ICD for API
 *      Parameters:   None
 *      Return Val:   None
 *******************************************************************/
void DSD_EPS::resetWatchdog()
{
  this->gpioLow(WDT_RESET);
  this->gpioHigh(WDT_RESET);
  this->gpioLow(WDT_RESET);
  this->gpioHigh(WDT_RESET);
}


/********************************************************************
 *   Private Set All PDMs On:
 *      Description:  See ICD for API
 *      Parameters:   None
 *      Return Val:   None
 *******************************************************************/
void DSD_EPS::allPDMsOn()
{
  this->gpioHigh(SW1_ENABLE);
  this->gpioHigh(SW2_ENABLE);
  this->gpioHigh(SW3_ENABLE);
  this->gpioHigh(SW4_ENABLE);
  this->gpioHigh(SW5_ENABLE);
  this->gpioHigh(VBAT_ENABLE);
}


/********************************************************************
 *   Private Set All PDMs Off:
 *      Description:  See ICD for API
 *      Parameters:   None
 *      Return Val:   None
 *******************************************************************/
void DSD_EPS::allPDMsOff()
{
  this->gpioLow(SW1_ENABLE);
  this->gpioLow(SW2_ENABLE);
  this->gpioLow(SW3_ENABLE);
  this->gpioLow(SW4_ENABLE);
  this->gpioLow(SW5_ENABLE);
  this->gpioLow(VBAT_ENABLE);
}


/********************************************************************
 *   Private Get Actual PDM Status:
 *      Description:  See ICD for API
 *      Parameters:   None
 *      Return Val:   None
 *******************************************************************/
void DSD_EPS::getPDMsActual()
{
  if (!this->i2c_request)
  {
    this->pdm_status = (digitalRead(SW1_ENABLE)) ? (this->pdm_status | 0x01) : (this->pdm_status & 0xFE);
    this->pdm_status = (digitalRead(SW2_ENABLE)) ? (this->pdm_status | 0x02) : (this->pdm_status & 0xFD);
    this->pdm_status = (digitalRead(SW3_ENABLE)) ? (this->pdm_status | 0x04) : (this->pdm_status & 0xFB);
    this->pdm_status = (digitalRead(SW4_ENABLE)) ? (this->pdm_status | 0x08) : (this->pdm_status & 0xF7);
    this->pdm_status = (digitalRead(SW5_ENABLE)) ? (this->pdm_status | 0x10) : (this->pdm_status & 0xEF);
    this->pdm_status = (digitalRead(VBAT_ENABLE)) ? (this->pdm_status | 0x20) : (this->pdm_status & 0xDF);
  }
  else
  {
    byte buffer_[2];
    buffer_[1] = this->pdm_status;
    buffer_[0] = 0x00;
    delay(1);
    I2C.write(buffer_, 2);
  }
}


/********************************************************************
 *   Private Get Expected PDMs:
 *      Description:  See ICD for API
 *      Parameters:   None
 *      Return Val:   None
 *******************************************************************/
void DSD_EPS::getPDMsExpected()
{
  byte buffer_[2];
  buffer_[1] = this->pdm_expected;
  buffer_[0] = 0x00;
  delay(1);
  I2C.write(buffer_, 2);
}


/********************************************************************
 *   Private Set PDM On:
 *      Description:  See ICD for API
 *      Parameters:   None
 *      Return Val:   None
 *******************************************************************/
void DSD_EPS::setPDMOn()
{
  switch(this->i2c_data[1])
  {
    case  1:
          this->gpioHigh(SW1_ENABLE);
          this->pdm_expected = this->pdm_expected | 0x01;
          break;
    case  2:
          this->gpioHigh(SW2_ENABLE);
          this->pdm_expected = this->pdm_expected | 0x02;
          break;
    case  3:
          this->gpioHigh(SW3_ENABLE);
          this->pdm_expected = this->pdm_expected | 0x04;
          break;
    case  4:
          this->gpioHigh(SW4_ENABLE);
          this->pdm_expected = this->pdm_expected | 0x08;
          break;
    case  5:
          this->gpioHigh(SW5_ENABLE);
          this->pdm_expected = this->pdm_expected | 0x10;
          break;
    case  6:
          this->gpioHigh(VBAT_ENABLE);
          this->pdm_expected = this->pdm_expected | 0x20;
          break;
    default:
          // FAULT
          break;
  }
}


/********************************************************************
 *   Private Set PDM Off:
 *      Description:  See ICD for API
 *      Parameters:   None
 *      Return Val:   None
 *******************************************************************/
void DSD_EPS::setPDMOff()
{
  switch(this->i2c_data[1])
  {
    case  1:
          this->gpioLow(SW1_ENABLE);
          this->pdm_expected = this->pdm_expected & 0xfe;
          break;
    case  2:
          this->gpioLow(SW2_ENABLE);
          this->pdm_expected = this->pdm_expected & 0xfd;
          break;
    case  3:
          this->gpioLow(SW3_ENABLE);
          this->pdm_expected = this->pdm_expected & 0xfb;
          break;
    case  4:
          this->gpioLow(SW4_ENABLE);
          this->pdm_expected = this->pdm_expected & 0xf7;
          break;
    case  5:
          this->gpioLow(SW5_ENABLE);
          this->pdm_expected = this->pdm_expected & 0xef;
          break;
    case  6:
          this->gpioLow(VBAT_ENABLE);
          this->pdm_expected = this->pdm_expected & 0xdf;
          break;
    default:
          // FAULT
          break;
  }
}


/********************************************************************
 *   Private Make the EPS Reset Using Watchdog:
 *      Description:  See ICD for API
 *      Parameters:   None
 *      Return Val:   None
 *******************************************************************/
void DSD_EPS::epsReset()
{
  this->reset_eps = true;
}


/********************************************************************
 *   Public Constructor:
 *      Description:  See ICD for API
 *      Parameters:   None
 *      Return Val:   Pointer
 *******************************************************************/
DSD_EPS::DSD_EPS()
{
  // No constructor because arduinos can't handle it
}


/********************************************************************
 *   Public Deconstructor:
 *      Description:  See ICD for API
 *      Parameters:   None
 *      Return Val:   Null Pointer
 *******************************************************************/
DSD_EPS::~DSD_EPS()
{
  // No deconstructor required for this application
}

/********************************************************************
 *   Public Initializer:
 *      Description:  See ICD for API
 *      Parameters:   None
 *      Return Val:   None
 *******************************************************************/
void DSD_EPS::init()
{
  /********************************************************************
   *   Establish Default Status to Keep the EPS ON
   *******************************************************************/
  this->reset_eps = false;
  
  /********************************************************************
   *   Establish Default Pin Modes
   *******************************************************************/
  pinMode(WDT_RESET, OUTPUT);
  pinMode(I2C_ENABLE, OUTPUT);
  pinMode(SW1_ENABLE, OUTPUT);
  pinMode(SW2_ENABLE, OUTPUT);
  pinMode(SW3_ENABLE, OUTPUT);
  pinMode(SW4_ENABLE, OUTPUT);
  pinMode(SW5_ENABLE, OUTPUT);
  pinMode(VBAT_ENABLE, OUTPUT);
  
  /********************************************************************
   *   Establish Default Pin Values
   *******************************************************************/
  this->gpioHigh(WDT_RESET);
  this->gpioLow(I2C_ENABLE);
  this->gpioLow(SW1_ENABLE);
  this->gpioLow(SW2_ENABLE);
  this->gpioLow(SW3_ENABLE);
  this->gpioLow(SW4_ENABLE);
  this->gpioLow(SW5_ENABLE);
  this->gpioLow(VBAT_ENABLE);
  
  /********************************************************************
   *   Reset the Watchdog Timer
   *******************************************************************/
  this->resetWatchdog();
  this->watchdog_limit = (4.0 * 60.0 * 1000.0);
  this->watchdog_last_reset = millis();
  this->watchdog_internal = millis();
  
  /********************************************************************
   *   Place the EPS I2C Circuit on the CSKB Bus
   *******************************************************************/
  this->i2c_receive = false;
  this->i2c_request = false;
  this->gpioHigh(I2C_ENABLE);
  
}


/********************************************************************
 *   Public Read the I2C Bus:
 *      Description:  See ICD for API
 *      Parameters:   None
 *      Return Val:   None
 *******************************************************************/
void DSD_EPS::readI2C()
{
  switch(this->i2c_data[0])
  {
    case  BOARD_STATUS:
          this->boardStatus();
          break;
    case  GET_LAST_ERROR:
          this->getLastError();
          break;
    case  GET_VERSION:
          this->getVersion();
          break;
    case  GET_TELEMETRY:
          this->getTelemetry();
          break;
    case  GET_WATCHDOG:
          this->getWatchdog();
          break;
    case  SET_WATCHDOG:
          this->setWatchdog();
    case  RESET_WATCHDOG:
          this->resetWatchdog();
          this->watchdog_last_reset = millis();
          break;
    case  ALL_PDMS_ON:
          this->allPDMsOn();
          break;
    case  ALL_PDMS_OFF:
          this->allPDMsOff();
          break;
    case  GET_PDMS_ACTUAL:
          this->getPDMsActual();
          break;
    case  GET_PDMS_EXPECTED:
          this->getPDMsExpected();
          break;
    case  SET_PDM_ON:
          this->setPDMOn();
          break;
    case  SET_PDM_OFF:
          this->setPDMOff();
          break;
    case  EPS_RESET:
          this->epsReset();
          break;
    default:
          this->board_status = this->board_status | 0x01;
          this->last_error = 0x13;
          break;
  }
  
  if (this->i2c_request)
  {
    this->i2c_request = false;
  }
}


/********************************************************************
 *   Public Read the UART Connection:
 *      Description:  See ICD for API
 *      Parameters:   None
 *      Return Val:   None
 *******************************************************************/
void DSD_EPS::readUART()
{
  // Future implementation using UART for command and control
}
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
void loop() 
{
  while (true)
  {
    /********************************************************************
     *   Monitor the Watchdog
     *******************************************************************/
    eps.watchdog();
  }
}

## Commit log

2020-11-30 init commit
    [BOM.xlsx, EPS.brd, EPS.sch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]
2020-11-30 merged with v0.4.0
    [BOM.xlsx, EPS.brd, EPS.sch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]
2021-01-22 verified working
    [eps_version_0.4.0.brd, eps_version_0.4.0.sch]
2021-01-22 synced files
    [eps_version_0.4.0.brd, eps_version_0.4.0.sch]
2021-01-29 fixed BCR
    [BOM.xlsx]

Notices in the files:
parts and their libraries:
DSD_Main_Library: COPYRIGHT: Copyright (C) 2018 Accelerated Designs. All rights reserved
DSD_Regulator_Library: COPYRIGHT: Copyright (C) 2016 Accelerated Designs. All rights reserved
